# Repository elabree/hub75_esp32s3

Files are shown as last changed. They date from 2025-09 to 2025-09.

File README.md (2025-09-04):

# hub75_esp32s3
This PCBA provides an USB-C interface for HUB75E connection based RGB LED panels. It uses a [ESP32-S3-WROOM-1-N16R8](https://www.espressif.com/sites/default/files/documentation/esp32-s3-wroom-1_wroom-1u_datasheet_en.pdf) module which includes a ESP32-S3 processor and additional memory:
- Flash: 16 MB (Quad SPI)
- PSRAM: 8 MB (Octal SPI)

## Manufacturing & Assembly
All necessary components use Surface Mount Technology. The complete hub75_esp32s3 hardware including soldering can be ordered at a proto manufacturer like [JLCPCB](https://jlcpcb.com/capabilities/pcb-assembly-capabilities).

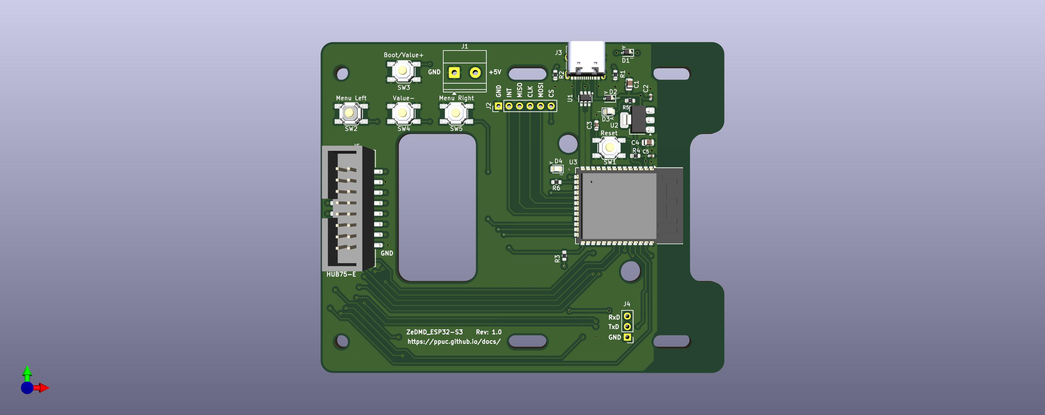
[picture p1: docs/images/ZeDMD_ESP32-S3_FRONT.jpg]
hub75_esp32s3


## Optional connectors
The following **optional** through hole connectors can be hand-soldered:
- J1: A Screw_Terminal block (pitch 5.08mm) for external 5V power supply input.
- J2: A 6 pin header (pitch 2.54 mm) connected to GPIO/SPI pins.
- J4: A 3 pin connection (pitch 2.54 mm) connected to UART0.

*These connectors are **not needed** when the PCBA is used for ZeDMD*

## Mounting
The PCBA has oval mounting holes to help with the mechanical alignment of two P2.5 160x80mm RGB LED Panels (64x32).

## Wiring
Most vendors of LED panels include the required band cables and power cords. Connect the input of the 1st (rightmost) panel to J5. 

The output of the 1st panel can be reached via the hole in the hub75_esp32s3 PCBA and needs to be connected to the input of the second panel. It is preferred to keep the cable away from the WiFi antenna of the ESP32 module to avoid interference.

## ZeDMD GPIO connections
ZeDMD uses the following IO signals to drive the HUB75-E connector.

### HUB-75E:

| ESP32-S3-N16R8 | HUB75 pins |
| ---  | --- |
| GPIO 4 | R1 |
| GPIO 6 | B1 |
| GPIO 7 | R2 |
| GPIO 16 | B2 |
| GPIO 18 | A |
| GPIO 3 | C |
| GPIO 41 | CLK |
| GPIO 2 | OE |
| GPIO 5 | G1 |
| GPIO 15 | G2 |
| GPIO 1 | E |
| GPIO 8 | B |
| GPIO 42 | D |
| GPIO 40 | LAT |

### Buttons:

| ESP32-S3-N16R8 | Menu Button |
| ---  | ---|
| GPIO 48 | Menu Left |
| GPIO 47 | Menu Right  |
| GPIO 0 | Value + |
| GPIO 45 | Value - |

## Other GPIO connections
The following IO signals are not used by ZeDMD.

### SPI:
| ESP32-S3-N16R8 | Function | Connector - pin |
| ---  | ---| --- |
| GPIO 10 | SPI_CS | J2 - 6 |
| GPIO 11 | SPI_MOSI | J2 - 5 |
| GPIO 12 | SPI_CLK | J2 - 4 |
| GPIO 13 | SPI_MISO | J2 - 3 |
| GPIO 14 | INTerrupt | J2 - 2 |
| GND | | J2 - 1 |

### UART0:
| ESP32-S3-N16R8 | Function | Connector - pin |
| ---  | ---| --- |
| RxD0 | serial in | J4 - 3 |
| TxD0 | serial out  | J4 - 2 |
| GND | | J4 - 1 |

### LED:
| ESP32-S3-N16R8 | Function |
| ---  | ---|
| GPIO 46 | Blue |

## Firmware
The hardware has been developed to run [ZeDMD](https://github.com/PPUC/ZeDMD) firmware.

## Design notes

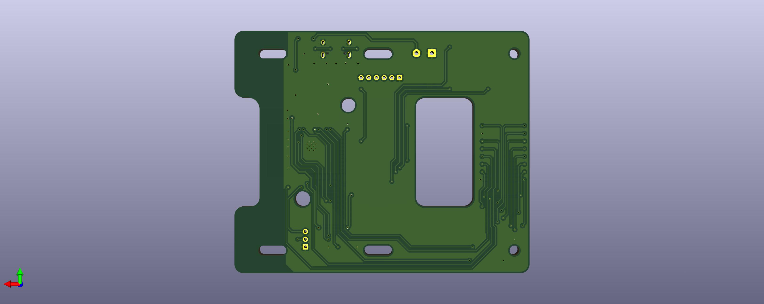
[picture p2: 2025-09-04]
docs/images/ZeDMD_ESP32-S3_BACK.jpg

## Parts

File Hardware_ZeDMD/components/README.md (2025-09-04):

## LCSC partnumbers
[JLCPCB Assembly Parts Lib](https://jlcpcb.com/parts)

| Comment | LCSC |
| --- | --- |
| KH-TYPE-C-16P - USB-C receptable connector | C709357 |
| 2x8p IDC Header, SMD vertical, P=2.54mm | C601969 |
| TS-1187A-B-A-B, tacticle switch, 5.1x5.1mm | C318884 |
| KT-0805G - Led green, 230 mcd @ 20 mA | C2297 |
| KT-0805B - Led blue, 55 mcd @ 20 mA | C2293 |
| 100 ohm, 100mW Thick Film Resistor, 1% | C22775 |
| 470 ohm, 100mW Thick Film Resistor, 1% | C23179 |
| 5k1, 100mW Thick Film Resistor, 1% | C23186 |
| ESP32-S3-WROOM-1-N16R8 SoC | C2913202  |
| USBLC6-2SC6 - USB2 dataline protection TVS/ESD  | C7519 |
| 100nF X7R ±10% 16V | C1525 |
| 2.2uF X5R ±10% 16V | C23630 |
| 10uF X5R ±10% 25V | C15850 |
| AMS1117-3.3 LDO, +3.3V fixed output | C5346136  |

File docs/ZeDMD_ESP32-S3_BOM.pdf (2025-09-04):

ZeDMD_ESP32-S3

Reference | Qty | Value | DNP | Footprint | Description | LCSC
C1,C4 | | 2 10uF | | Capacitor_SMD:C_0805_2012Metric | 10uF X5R ±10% 25V | C15850
C2,C5 | | 2 100nF | | Capacitor_SMD:C_0402_1005Metric | 100nF X7R ±10% 16V | C1525
C3 | | 1 2.2uF | | Capacitor_SMD:C_0603_1608Metric | 2.2uF X5R ±10% 16V | C23630
D1,D2 | | 2 1N5819WS | | Diode_SMD:D_SOD-323 | 1N5819WS - 1A Schottky Diode | C191023
D3 | | 1 KT-0805G | | LED_SMD:LED_0805_2012Metric | KT-0805G - Led green, 230 mcd @ 20 mA | C2297
D4 | | 1 KT-0805B | | LED_SMD:LED_0805_2012Metric | KT-0805B - Led blue, 55 mcd @ 20 mA | C2293
J1 | 1 Screw_Terminal_01x02 | DNP | TerminalBlock_Phoenix:TerminalBlock_Phoenix_MKDS-1,5-2-5.08_1x02_P5.08mm_Horizontal | Generic screw terminal, single row, 01x02, script generated (kicad-library-utils/schlib/autogen/connector/)
J2 | | 1 Conn_01x06_Pin | DNP | Connector_PinHeader_2.54mm:PinHeader_1x06_P2.54mm_Vertical | Generic connector, single row, 01x06, script generated
J3 | | 1 USB_C_Receptacle_USB2.0_16P | | Connector_USB:USB_C_Receptacle_XKB_U262-16XN-4BVC11 | KH-TYPE-C-16P - USB-C receptable connector | C709357
J4 | | 1 Conn_01x03_Pin | DNP | Connector_PinHeader_2.54mm:PinHeader_1x03_P2.54mm_Vertical | Generic connector, single row, 01x03, script generated
J5 | | 1 Conn_02x08_Odd_Even | | Connector_IDC:IDC-Header_2x08_P2.54mm_Vertical_SMD | 2x8p IDC Header, SMD vertical, P=2.54mm | C601969
R1,R2,R3,R4 | | 4 5k1 | | Resistor_SMD:R_0603_1608Metric | 5k1, 100mW Thick Film Resistor, 1% | C23186
R5 | | 1 470 | | Resistor_SMD:R_0603_1608Metric | 470 ohm, 100mW Thick Film Resistor, 1% | C23179
R6 | | 1 100 | | Resistor_SMD:R_0603_1608Metric | 100 ohm, 100mW Thick Film Resistor, 1% | C22775
SW1 | | 1 Reset | | Button_Switch_SMD:SW_SPST_SKQG_WithStem | TS-1187A-B-A-B, tacticle switch, 5.1x5.1mm | C318884
SW2 | | 1 Menu Left | | Button_Switch_SMD:SW_SPST_SKQG_WithStem | TS-1187A-B-A-B, tacticle switch, 5.1x5.1mm | C318884
SW3 | | 1 Boot/Value+ | | Button_Switch_SMD:SW_SPST_SKQG_WithStem | TS-1187A-B-A-B, tacticle switch, 5.1x5.1mm | C318884
SW4 | | 1 Value- | | Button_Switch_SMD:SW_SPST_SKQG_WithStem | TS-1187A-B-A-B, tacticle switch, 5.1x5.1mm | C318884
SW5 | | 1 Menu Right | | Button_Switch_SMD:SW_SPST_SKQG_WithStem | TS-1187A-B-A-B, tacticle switch, 5.1x5.1mm | C318884
U1 | | 1 USBLC6-2SC6 | | Package_TO_SOT_SMD:SOT-23-6 | USBLC6-2SC6 - USB2 dataline protection TVS/ESD | C7519
U2 | | 1 AMS1117-3.3 | | Package_TO_SOT_SMD:SOT-223-3_TabPin2 | AMS1117-3.3 LDO, +3.3V fixed output | C5346136
U3 | | 1 ESP32-S3-WROOM-1 | | RF_Module:ESP32-S3-WROOM-1 | ESP32-S3-WROOM-1-N16R8 SoC | C2913202
ZeDMD_ESP32-S3_BOM.xlsx | Pagina 1

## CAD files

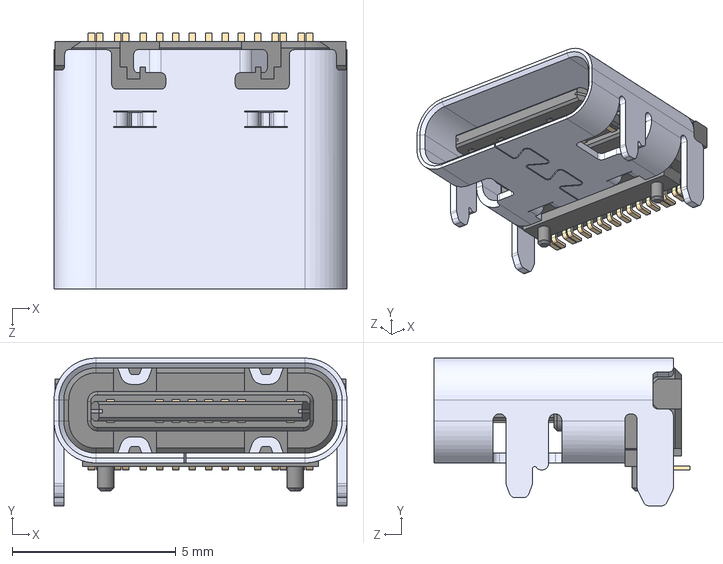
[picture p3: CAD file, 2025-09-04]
Hardware_ZeDMD/components/KH-TYPE-C-16P--3DModel-STEP-269445.STEP
8.94 x 4.51 x 7.81 mm

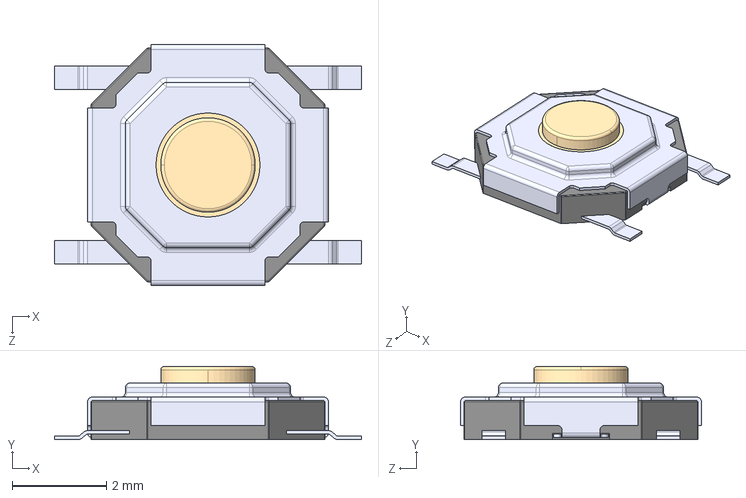
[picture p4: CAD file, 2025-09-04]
Hardware_ZeDMD/components/TS-1187A-B-A-B--3DModel-STEP-56544.STEP
6.50 x 1.55 x 5.10 mm

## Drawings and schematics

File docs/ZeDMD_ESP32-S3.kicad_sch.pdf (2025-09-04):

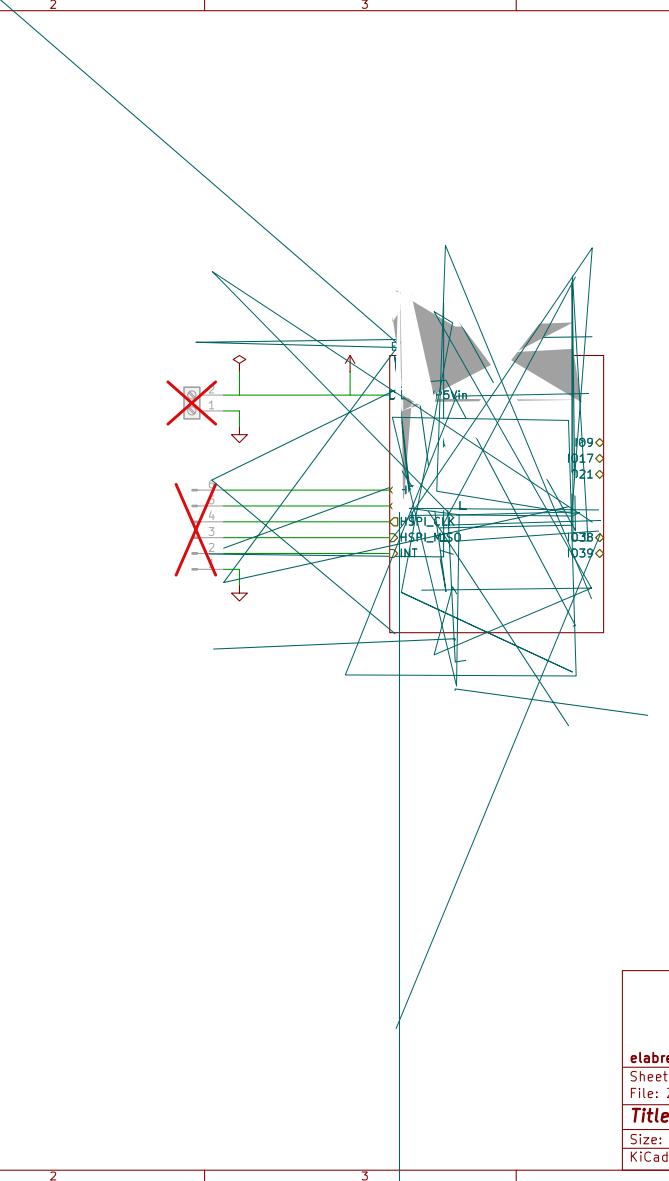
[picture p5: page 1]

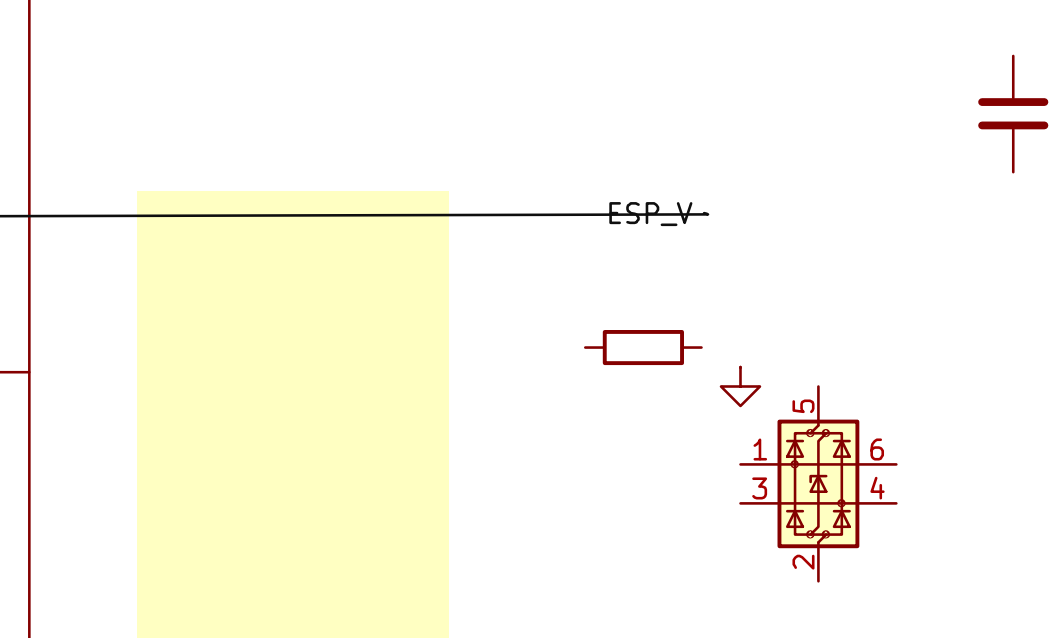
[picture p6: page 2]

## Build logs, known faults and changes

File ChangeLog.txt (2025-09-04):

2025-08-27  elabree
Rev1.0	Initial Version
